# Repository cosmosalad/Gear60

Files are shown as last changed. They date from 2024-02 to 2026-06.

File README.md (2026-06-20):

[▶ Check Out GearSeries](https://github.com/cosmosalad/GearSeries)<br/>
[프로젝트 과정(kr)](https://blog.naver.com/cosmosalad/223262540878)<br/><br/>

# Gear60<br/>
Gear60 is a 60% multi-layout keyboard based on the rp2040.
<br/>

It's mostly compatible with 60% layout keyboards. Just modify usb and plate to suit your keyboard housing

<br/>

<p align="center">
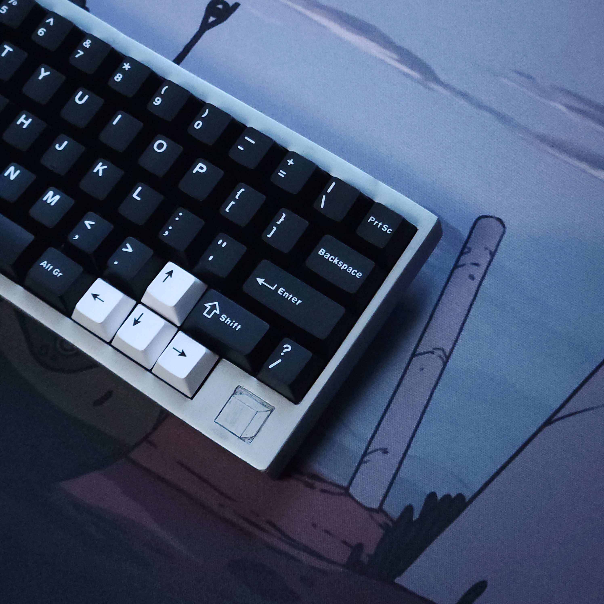
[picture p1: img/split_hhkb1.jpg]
  
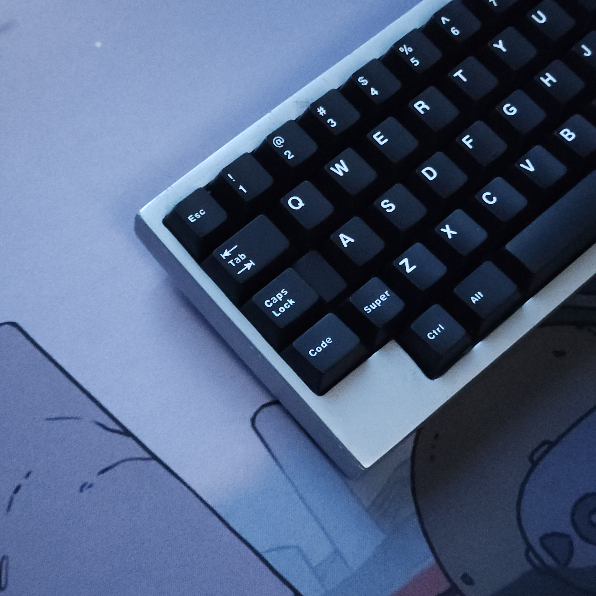
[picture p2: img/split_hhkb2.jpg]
  
</p>
<p align="center">
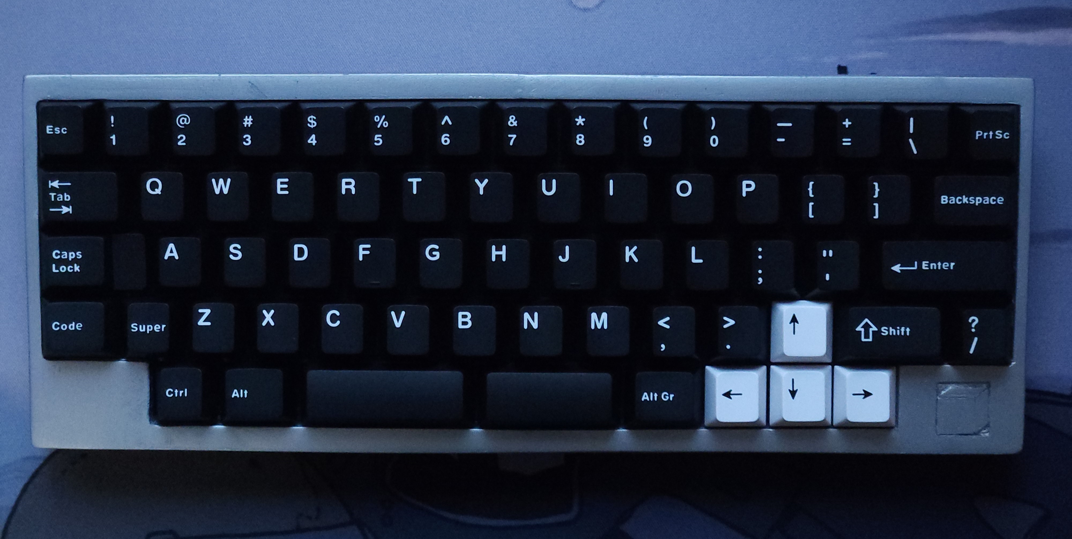
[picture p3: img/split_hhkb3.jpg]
  
</p>

split_hhkb (fdm print)

<br/><br/>

<p align="center">
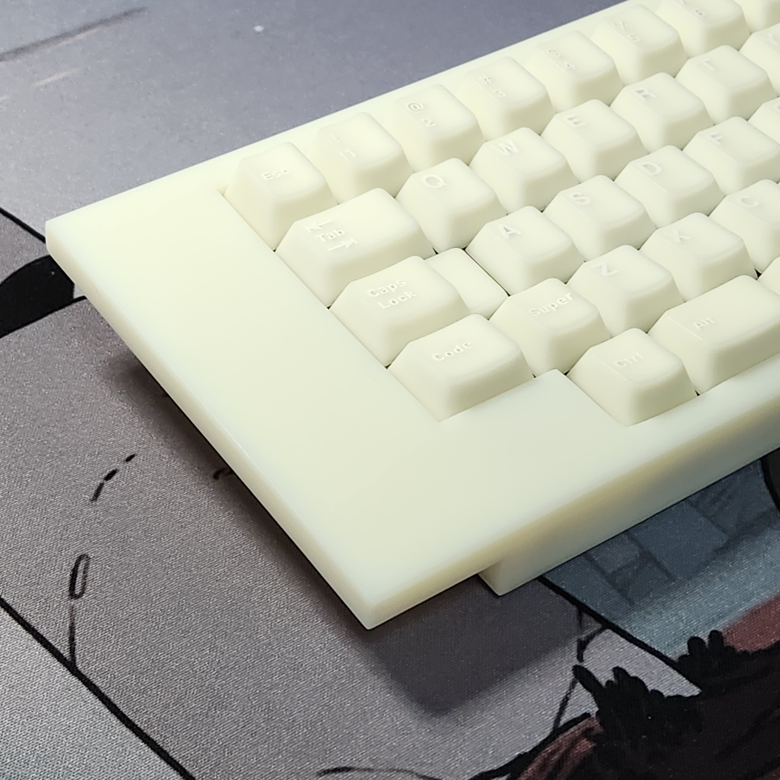
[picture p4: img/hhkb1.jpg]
  
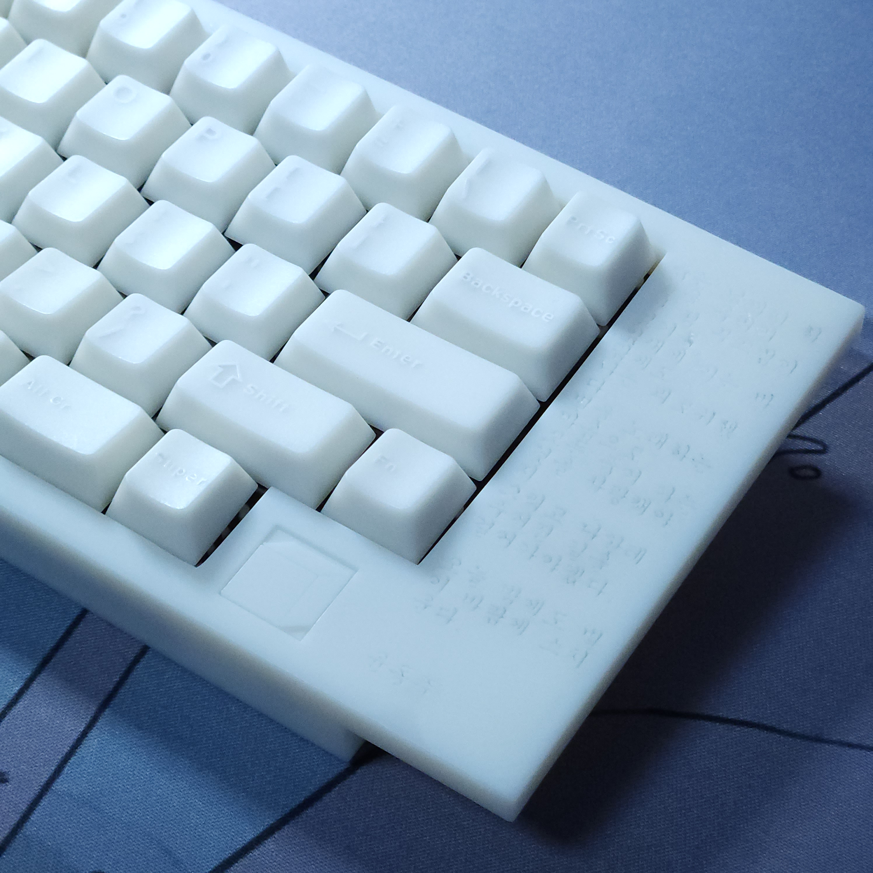
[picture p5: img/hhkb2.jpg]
  
</p>
<p align="center">
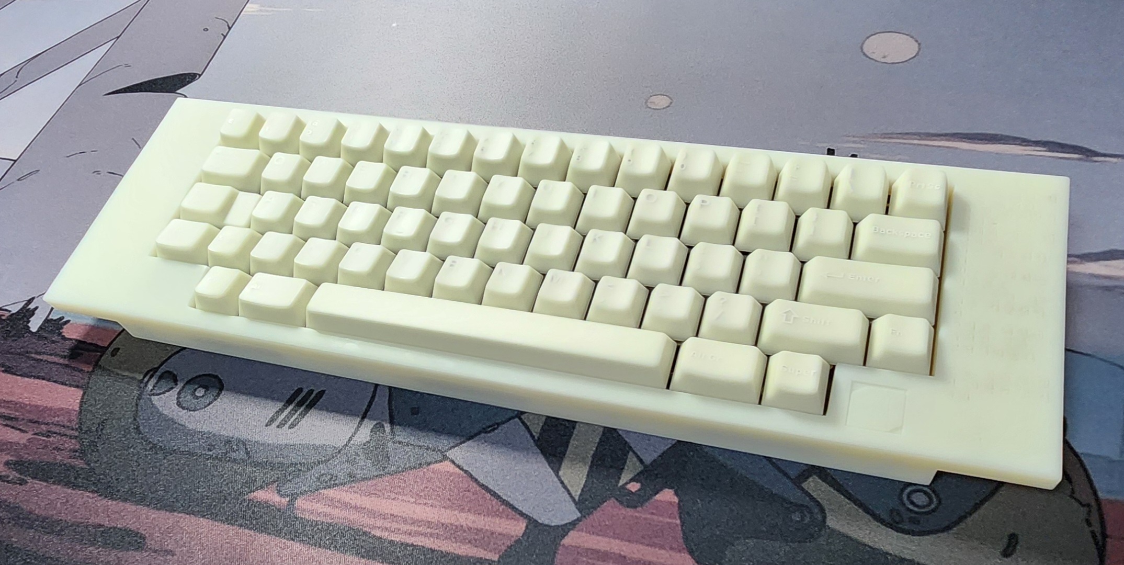
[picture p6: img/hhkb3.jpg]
  
</p>

hhkb - B type (sla print)

<br/><br/>

## Layout<br/>

- solder<br/>
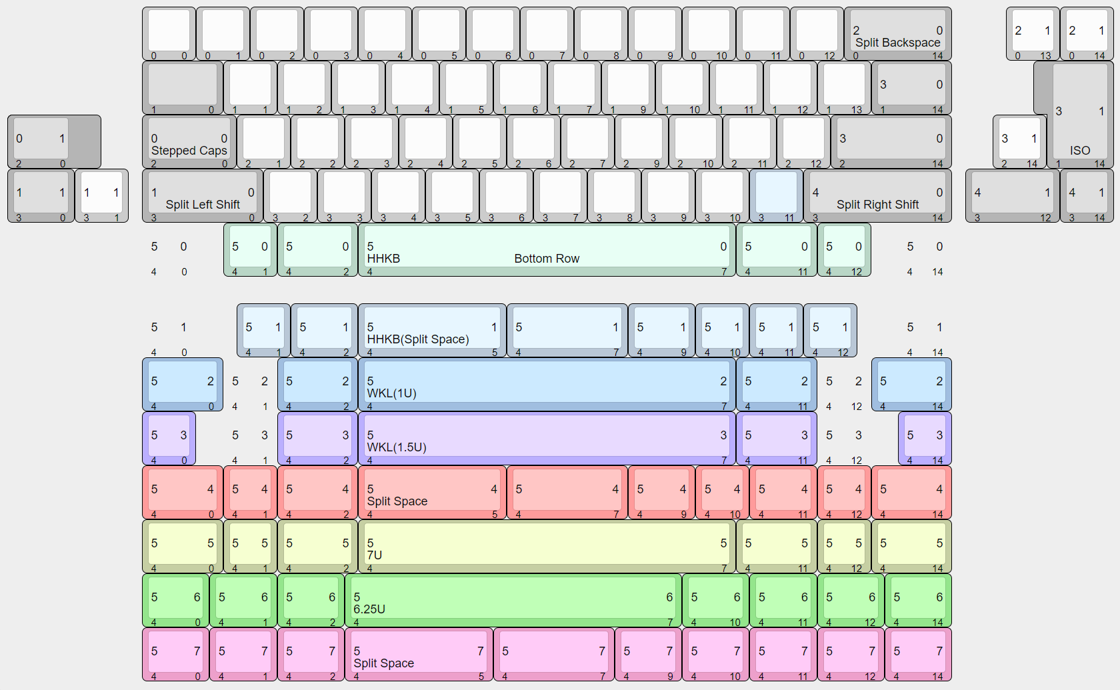
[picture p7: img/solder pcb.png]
solder pcb

<br/><br/>

- hotswap<br/>
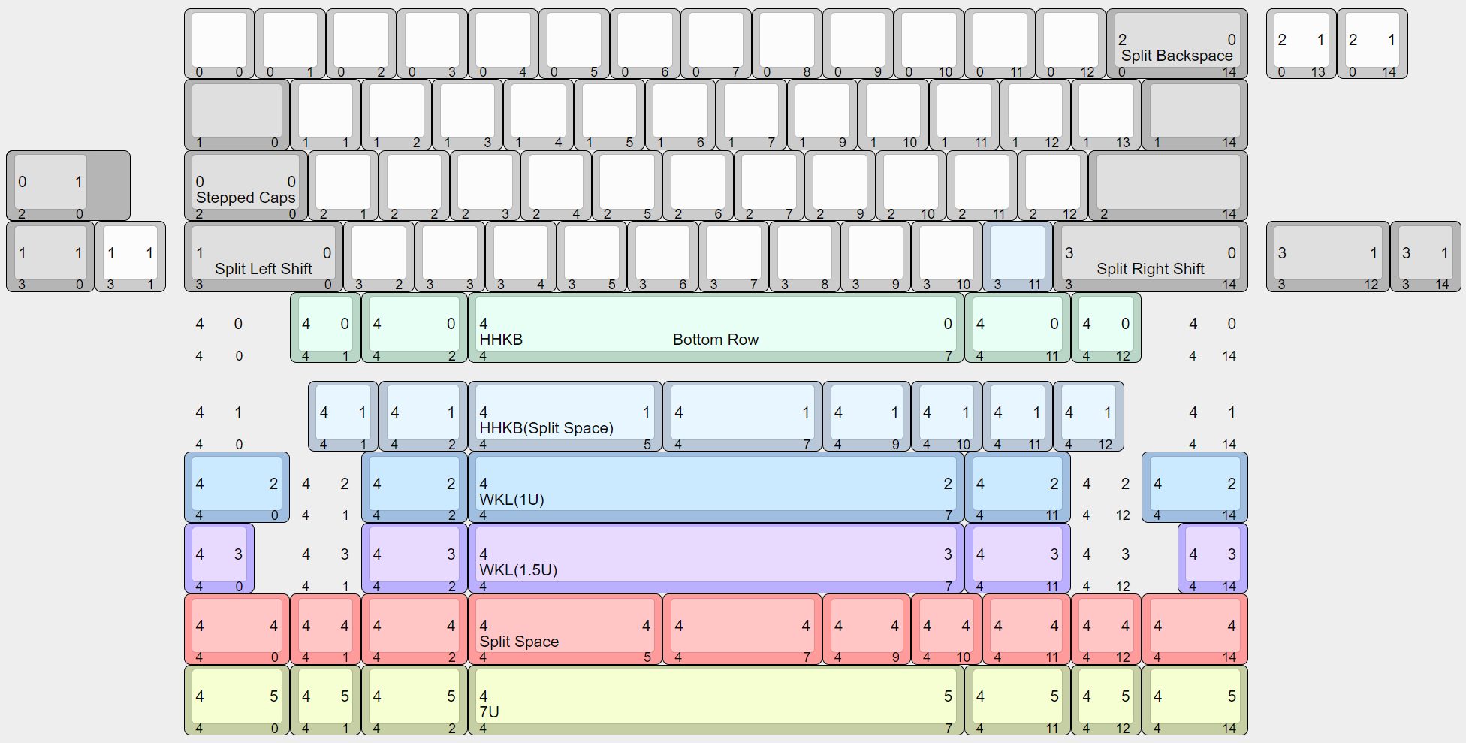
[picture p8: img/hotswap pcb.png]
hotswap pcb

<br/><br/>

There is also a [keyboard plate](https://github.com/cosmosalad/Gear60/tree/main/plate).<br/>
[Keyboard case](https://github.com/cosmosalad/Gear60/tree/main/case) corresponding to this layout.<br/>

<br/><br/>

## PCB<br/>
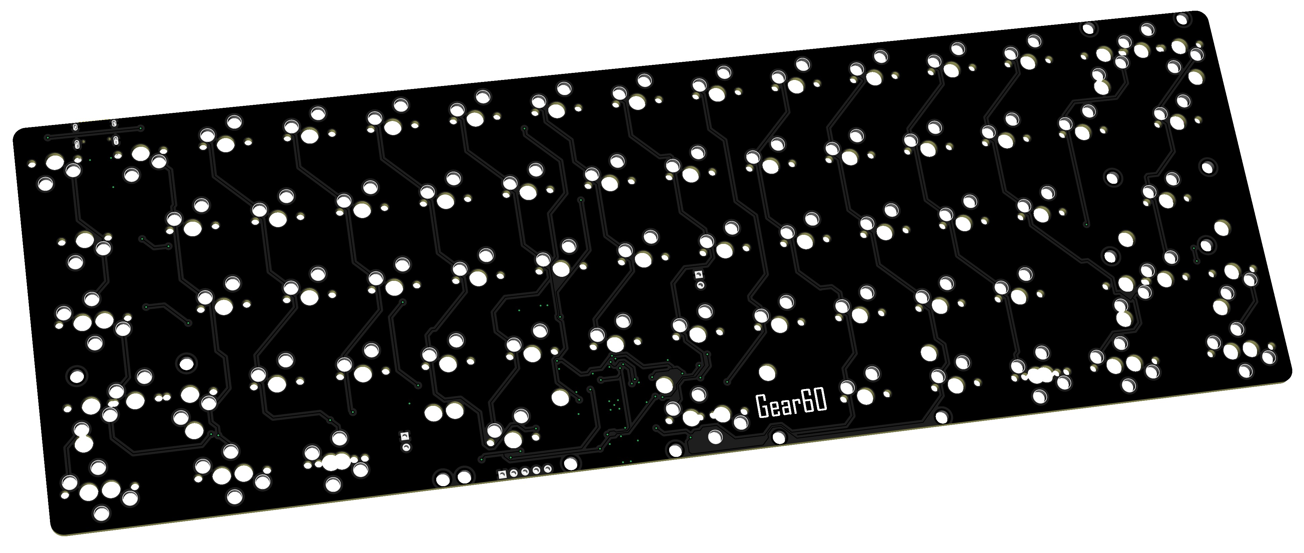
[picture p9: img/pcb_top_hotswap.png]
pcb_top_hotswap
<br/>
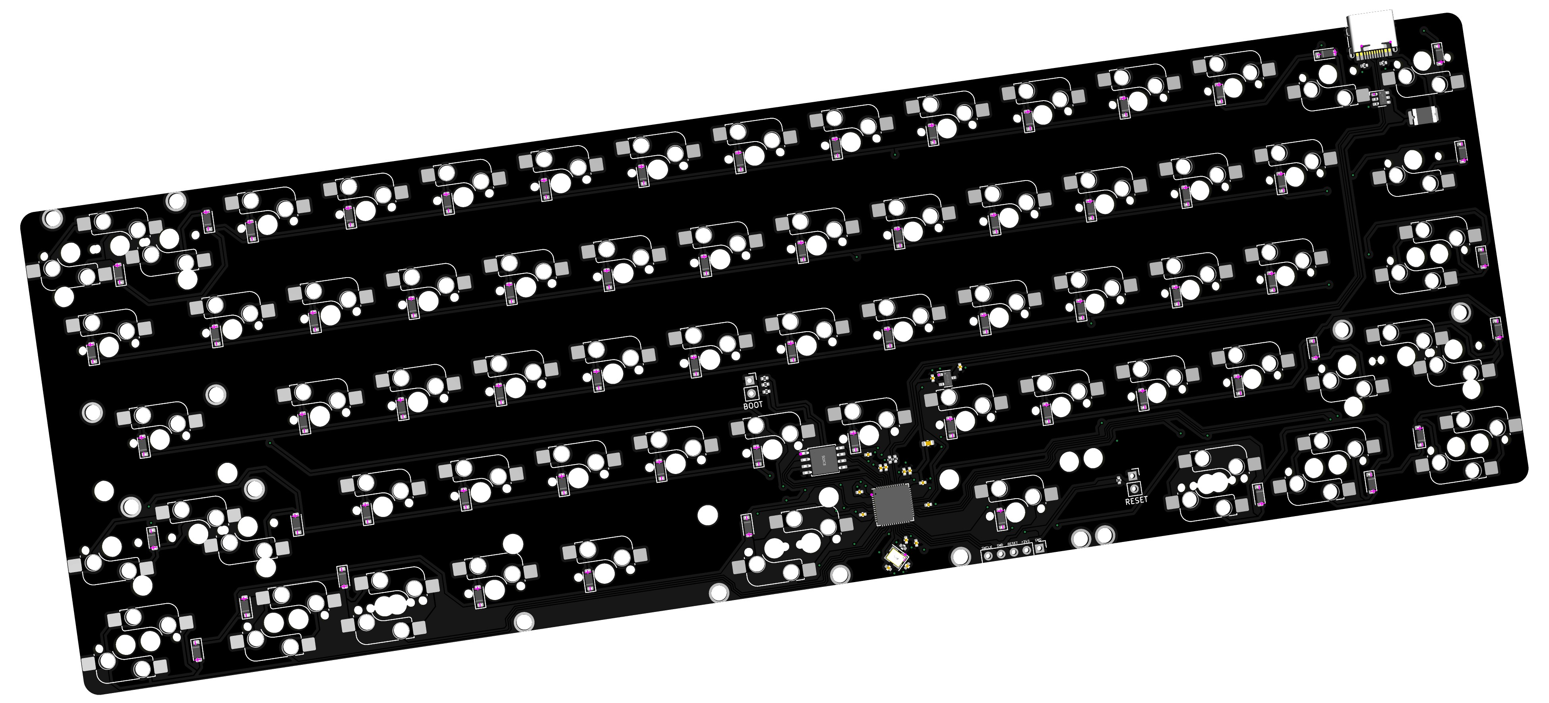
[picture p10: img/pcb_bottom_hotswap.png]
pcb_bottom_hotswap
<br/><br/><br/>

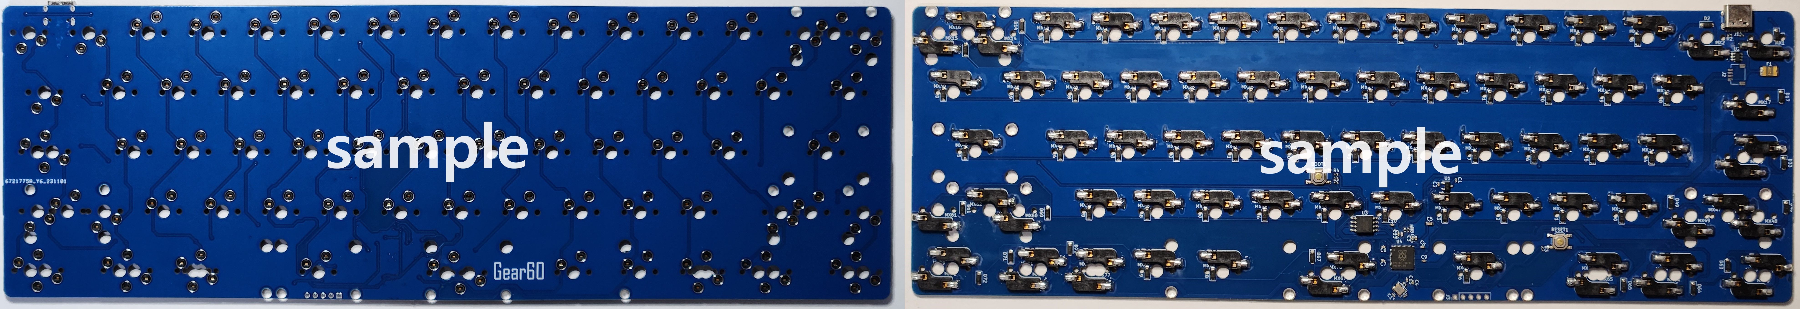
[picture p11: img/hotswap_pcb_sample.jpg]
hotswap_pcb_sample
<br/>
There is a change from the initial pcb design. [More pcb](https://github.com/cosmosalad/Gear60/tree/main/pcb)<br/><br/>
This pcb was made by jlcpcb.([list of pcb parts](https://github.com/cosmosalad/Gear60/blob/main/pcb/hotswap/part%20list.md))<br/><br/>
This pcb prepared the [vial](https://github.com/cosmosalad/Gear60/tree/main/vial) as firmware<br/><br/>

<p align="center">
  <a href="https://youtube.com/embed/gBcXavTLRE8">
    gear60
  </a>
</p>
<br/>

## Reference<br/>
- [keyboard-layout-editor](http://www.keyboard-layout-editor.com/)<br/>
- [Hardware design with RP2040](https://datasheets.raspberrypi.com/rp2040/hardware-design-with-rp2040.pdf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..), [Hardware design for the RP2040](https://github.com/Sleepdealr/RP2040-designguide)<br/>
- [kicad](https://www.kicad.org/), [marbastlib](https://github.com/ebastler/marbastlib), [kleeb](https://github.com/crides/kleeb)<br/>
- [KiCAD KLE Placer](https://github.com/zykrah/kicad-kle-placer), [Firmware 'scripts'](https://github.com/zykrah/firmware-scripts)<br/>
- [vial](https://get.vial.today/), [qmk](https://qmk.fm/)<br/>
- [ai03 Plate Generator v2](https://github.com/ai03-2725/yet-another-keyboard-builder)<br/>

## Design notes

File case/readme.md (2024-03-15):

### gear60_top_split_hhkb<br/>
gear60_top_split_hhkb
<br/><br/><br/><br/><br/>

### gear60_top_wkl<br/>
gear60_top_wkl
<br/><br/><br/><br/><br/>

### gear60_top<br/>
gear60_top
<br/><br/><br/><br/><br/>

### gear60_top_hhkb<br/>
gear60_top_hhkb
<br/><br/><br/><br/><br/>

### gear60_top_split_hhkb - A type<br/>
top_split_hhkb_a-type<br/>
a-type
<br/><br/><br/><br/><br/>

### gear60_top_hhkb - B type<br/>
top_hhkb_b-type
<br/><br/><br/><br/><br/>

### gear60_bottom<br/>
gear60_bottom
<br/><br/><br/><br/><br/>

### gear60_top_rp2040zero, bottom_rp2040zero<br/>
top_rp2040zero

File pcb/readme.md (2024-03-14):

### Gear60 hotswap<br/>
Gear60 hotswap<br/>

<br/><br/>

### Gear60 solder<br/>
Gear60 solder<br/>

<br/><br/>

### Gear60 solder_rp2040zero<br/>
solder_rp2040zero<br/>

<br/><br/>

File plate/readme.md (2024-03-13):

plate

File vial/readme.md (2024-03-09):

Hold the boot button and connect usb.<br/>

usb<br/>
After connecting to the keyboard, add the [uf2 file]https://github.com/cosmosalad/Gear60/tree/main/vial).<br/><br/><br/>

Open the [vial](https://vial.rocks/).<br/>
vial test<br/>
Key map<br/><br/>

test1<br/>
You can select the layout.<br/><br/>

test2<br/>

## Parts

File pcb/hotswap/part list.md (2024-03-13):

| **Comment** | **Designator** | **Footprint** | **JLCPCB Part #** |
|:---:|:---:|:---:|:---:|
| D_Small | ALL D | Diode_SMD:D_SOD-123 | C2099 |
| 22pF | C11,C12 | Capacitor_SMD:C_0402_1005Metric | C147430 |
| 10uF | C5 | Capacitor_SMD:C_0603_1608Metric | C19702 |
| 1uF | C1,C2,C3,C6,C10 | CAP-SMD_BD5.0-L5.3-W5.3-LS6.3-FD | C15684 |
| 100nF | C4,C7,C8,C9,C13,C14,C15,C16 | Capacitor_SMD:C_0402_1005Metric | C1525 |
| 27Ω | R7,R8 | Resistor_SMD:R_0402_1005Metric | C138021 |
| 5.1kΩ | R1,R2,R3,R4,R5 | Resistor_SMD:R_0402_1005Metric | C25905 |
| 1kΩ | R6,R9 | Resistor_SMD:R_0402_1005Metric | C11702 |
| RP2040 | U4 | Package_DFN_QFN:QFN-56-1EP_7x7mm_P0.4mm_EP3.2x3.2mm | C2040 |
| W25Q128JVS | U3 | Package_SO:SOIC-8_5.23x5.23mm_P1.27mm | C97521 |
| USB_C_Receptacle_USB2.0 | J1 | Connector_USB:USB_C_Receptacle_HRO_TYPE-C-31-M-12 | C165948 |
| XC6206P332MR	 | U1 | Package_TO_SOT_SMD:SOT-23-3 | C5446 |
| Crystal_GND24 | Y1 | Crystal:Crystal_SMD_3225-4Pin_3.2x2.5mm | C9002 |
| SRV05-4 | U2 | PCM_marbastlib-various:SOT-23-6-routable | C7420376 |
| MF-MSMF050-2500mA | F1 | Fuse:Fuse_0603_1608Metric | C17313 |

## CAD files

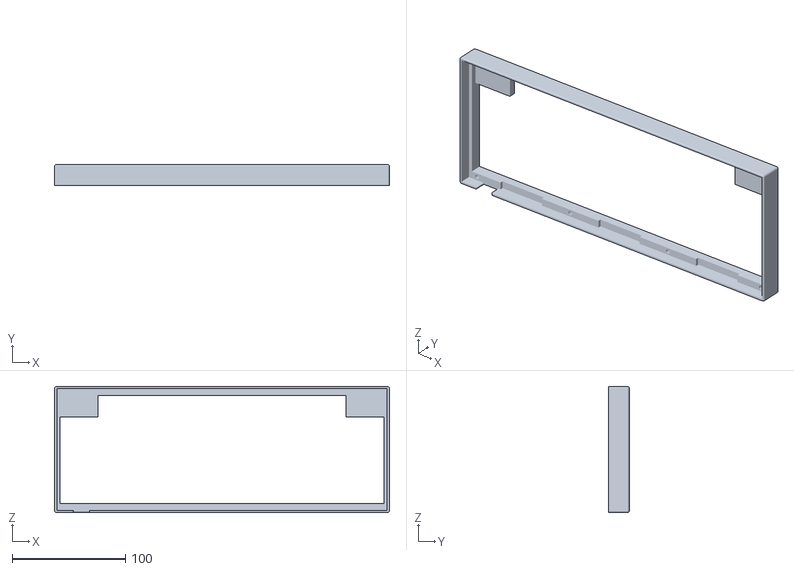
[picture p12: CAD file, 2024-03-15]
case/top_split_hhkb.stl
296.2 x 19.0 x 111.4

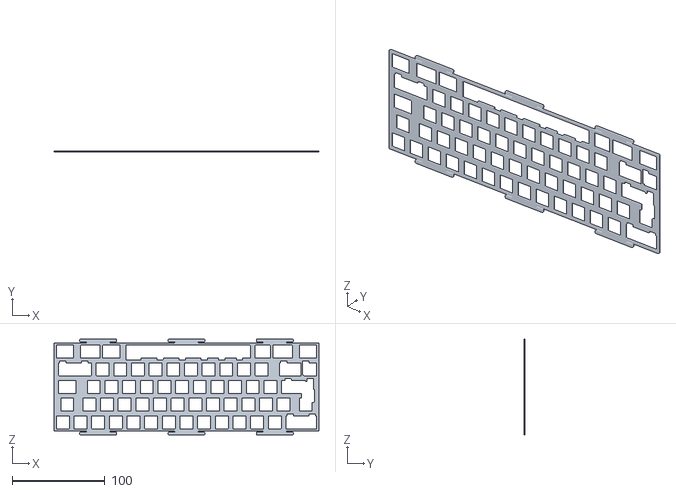
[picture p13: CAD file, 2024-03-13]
plate/gear60_plate.stl
285.8 x 1.50 x 103.2

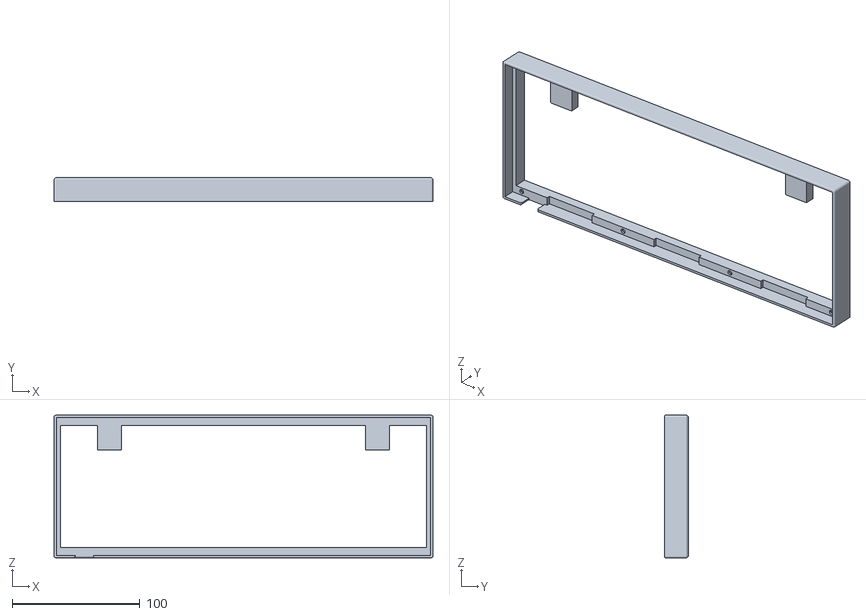
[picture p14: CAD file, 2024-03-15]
case/top_wkl.stl
296.2 x 19.0 x 111.4

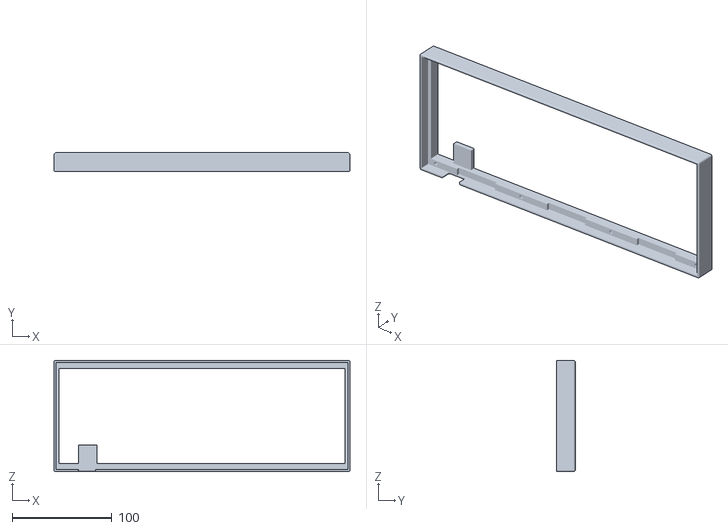
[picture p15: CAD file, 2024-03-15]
case/top_rp2040zero.stl
296.2 x 19.0 x 111.4

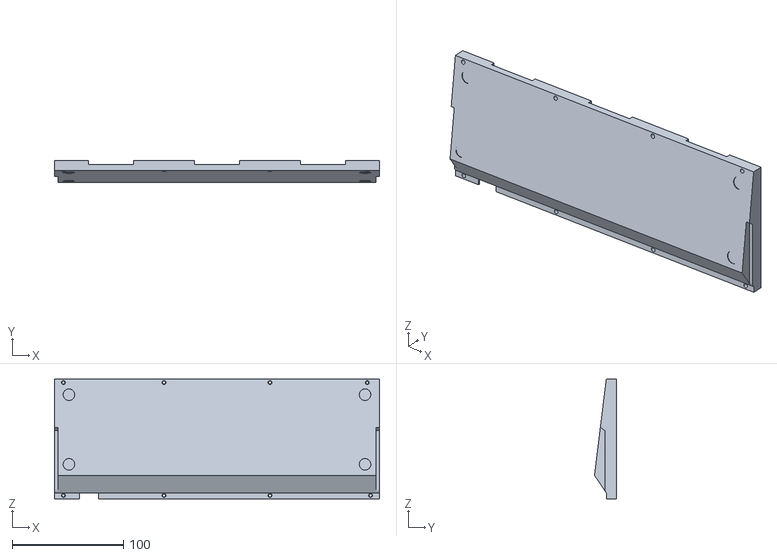
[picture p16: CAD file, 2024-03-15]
case/bottom_rp2040zero.stl
292.2 x 19.9 x 107.4

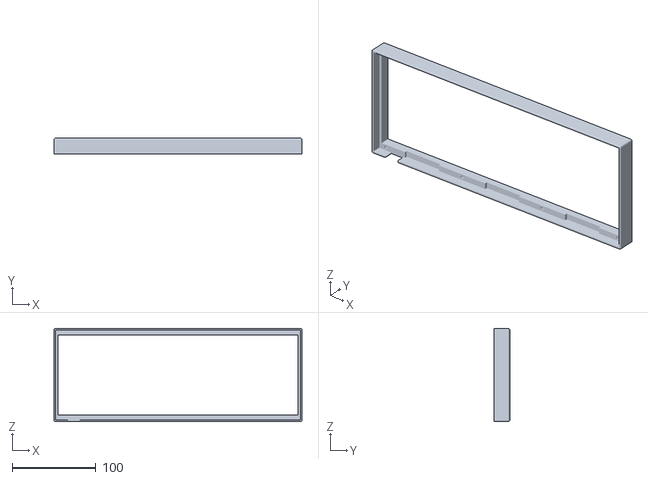
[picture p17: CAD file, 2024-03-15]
case/top.stl
296.2 x 19.0 x 111.4

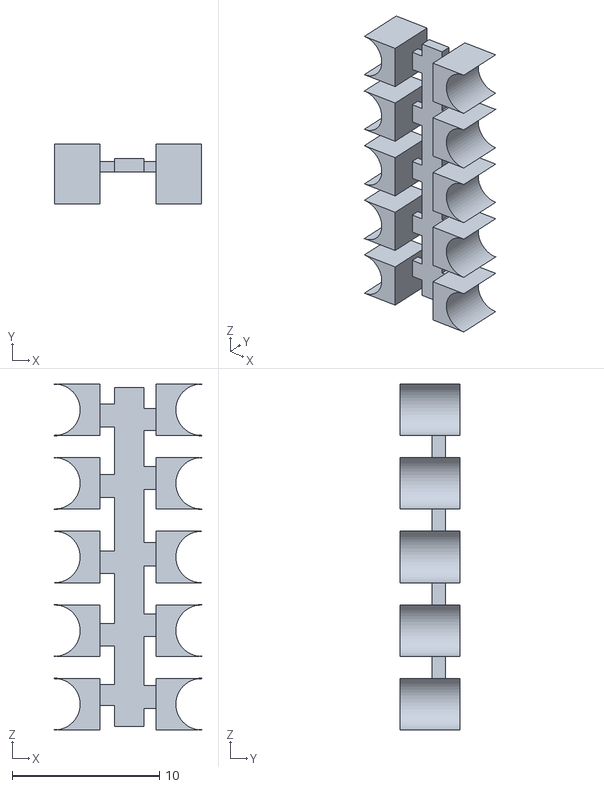
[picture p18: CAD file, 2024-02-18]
case/a-type.stl
10.0 x 4.10 x 23.5

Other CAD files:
case/top_hhkb.stl
case/top_split_hhkb_a-type.stl
case/bottom.stl
plate/gear60_plate.dxf

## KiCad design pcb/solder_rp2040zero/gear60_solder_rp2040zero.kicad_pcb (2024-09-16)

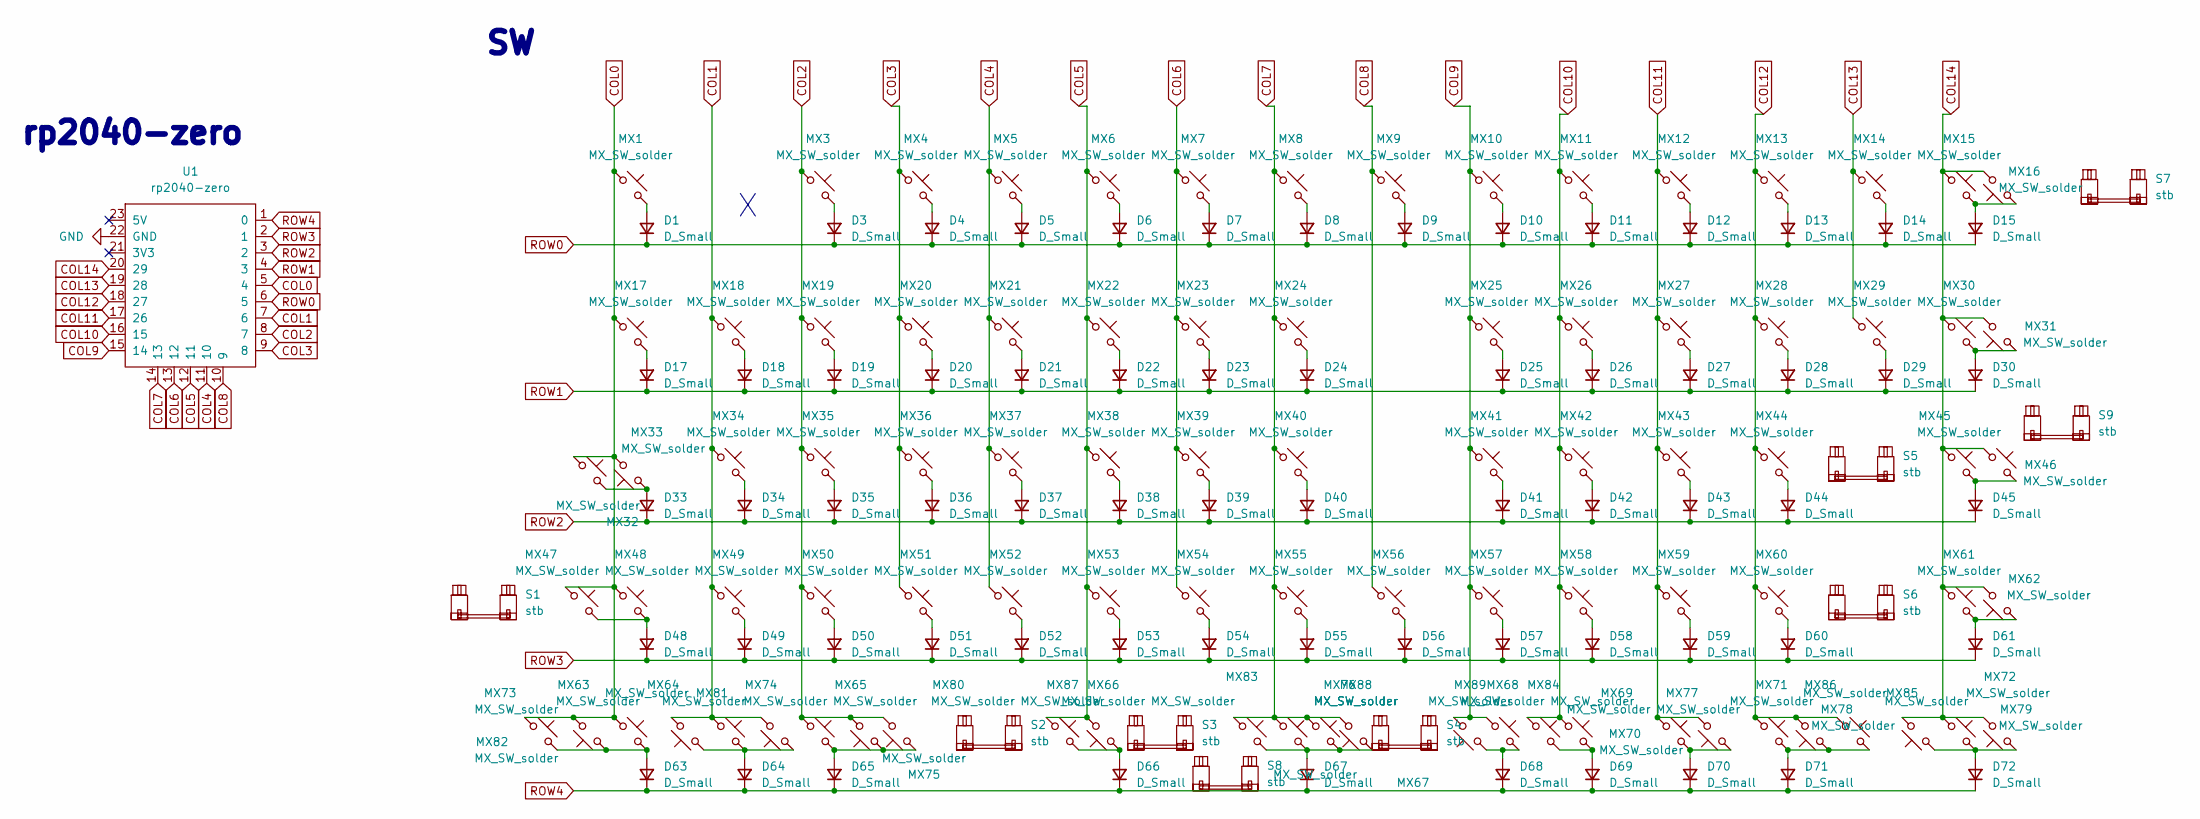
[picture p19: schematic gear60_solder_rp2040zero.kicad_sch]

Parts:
D1, D3, D4, D5, D6, D7, D8, D9, D10, D11, D12, D13, D14, D15, D17, D18, D19, D20, D21, D22, D23, D24, D25, D26, D27, D28, D29, D30, D33, D34, D35, D36, D37, D38, D39, D40, D41, D42, D43, D44, D45, D48, D49, D50, D51, D52, D53, D54, D55, D56, D57, D58, D59, D60, D61, D63, D64, D65, D66, D67, D68, D69, D70, D71, D72: D_Small; D_SOD-123
MX1, MX3, MX4, MX5, MX6, MX7, MX8, MX9, MX10, MX11, MX12, MX13, MX14, MX15, MX16, MX18, MX19, MX20, MX21, MX22, MX23, MX24, MX25, MX26, MX27, MX28, MX29, MX31, MX34, MX35, MX36, MX37, MX38, MX39, MX40, MX41, MX42, MX43, MX44, MX45, MX46, MX47, MX49, MX50, MX51, MX52, MX53, MX54, MX55, MX56, MX57, MX58, MX59, MX61, MX62, MX63, MX64, MX66, MX67, MX69, MX70, MX71, MX72, MX74, MX76, MX78, MX83, MX87, MX88, MX89: MX_SW_solder; SW_MX_1u
MX17, MX30, MX73, MX75, MX79: MX_SW_solder; SW_MX_1.5u
MX32: MX_SW_solder; SW_MX_1.75u_STP_1.25
MX33, MX60: MX_SW_solder; SW_MX_1.75u
MX48, MX65, MX68, MX77, MX80, MX81, MX82, MX84, MX85, MX86: MX_SW_solder; SW_MX_1.25u
S1, S3, S5: stb; STAB_MX_P_2.25u
S2, S6: stb; STAB_MX_P_2.75u
S4: stb; STAB_MX_P_7u
S7: stb; STAB_MX_P_2u
S8: stb; STAB_MX_P_6.25u
S9: stb; STAB_MX_ISO
U1: rp2040-zero; rp2040-zero-tht-new_long

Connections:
COL0: MX1.1, MX17.1, MX32.1, MX33.2, MX47.1, MX48.1, MX63.1, MX73.2, MX82.1, U1.5 (4)
COL1: MX18.1, MX34.1, MX49.1, MX64.1, MX74.2, MX81.2, U1.7 (6)
COL2: MX3.1, MX19.1, MX35.1, MX50.1, MX65.1, MX75.2, MX80.2, U1.8 (7)
COL3: MX4.1, MX20.1, MX36.1, MX51.1, U1.9 (8)
COL4: MX5.1, MX21.1, MX37.1, MX52.1, U1.11 (10)
COL5: MX6.1, MX22.1, MX38.1, MX53.1, MX66.2, MX87.1, U1.12 (11)
COL6: MX7.1, MX23.1, MX39.1, MX54.1, U1.13 (12)
COL7: MX8.1, MX24.1, MX40.1, MX55.1, MX67.1, MX76.1, MX83.1, MX88.2, U1.14 (13)
COL8: MX9.1, MX56.1, U1.10 (9)
COL9: MX10.1, MX25.1, MX41.1, MX57.1, MX68.1, MX89.2, U1.15 (14)
COL10: MX11.1, MX26.1, MX42.1, MX58.1, MX69.1, MX84.1, U1.16 (15)
COL11: MX12.1, MX27.1, MX43.1, MX59.1, MX70.1, MX77.2, U1.17 (26)
COL12: MX13.1, MX28.1, MX44.1, MX60.1, MX71.1, MX78.2, MX86.1, U1.18 (27)
COL13: MX14.1, MX29.1, U1.19 (28)
COL14: MX15.1, MX16.2, MX30.1, MX31.2, MX45.1, MX46.1, MX61.1, MX62.2, MX72.1, MX79.2, MX85.2, U1.20 (29)
GND: U1.22 (GND)
unnamed: D1.2 (A), MX1.2
unnamed: D3.2 (A), MX3.2
unnamed: D4.2 (A), MX4.2
unnamed: D5.2 (A), MX5.2
unnamed: D6.2 (A), MX6.2
unnamed: D7.2 (A), MX7.2
unnamed: D8.2 (A), MX8.2
unnamed: D9.2 (A), MX9.2
unnamed: D10.2 (A), MX10.2
unnamed: D11.2 (A), MX11.2
unnamed: D12.2 (A), MX12.2
unnamed: D13.2 (A), MX13.2
unnamed: D14.2 (A), MX14.2
unnamed: D15.2 (A), MX15.2, MX16.1
unnamed: D17.2 (A), MX17.2
unnamed: D18.2 (A), MX18.2
unnamed: D19.2 (A), MX19.2
unnamed: D20.2 (A), MX20.2
unnamed: D21.2 (A), MX21.2
unnamed: D22.2 (A), MX22.2
unnamed: D23.2 (A), MX23.2
unnamed: D24.2 (A), MX24.2
unnamed: D25.2 (A), MX25.2
unnamed: D26.2 (A), MX26.2
unnamed: D27.2 (A), MX27.2
unnamed: D28.2 (A), MX28.2
unnamed: D29.2 (A), MX29.2
unnamed: D30.2 (A), MX30.2, MX31.1
unnamed: D33.2 (A), MX32.2, MX33.1
unnamed: D34.2 (A), MX34.2
unnamed: D35.2 (A), MX35.2
unnamed: D36.2 (A), MX36.2
unnamed: D37.2 (A), MX37.2
unnamed: D38.2 (A), MX38.2
unnamed: D39.2 (A), MX39.2
unnamed: D40.2 (A), MX40.2
unnamed: D41.2 (A), MX41.2
unnamed: D42.2 (A), MX42.2
unnamed: D43.2 (A), MX43.2
unnamed: D44.2 (A), MX44.2
unnamed: D45.2 (A), MX45.2, MX46.2
unnamed: D48.2 (A), MX47.2, MX48.2
unnamed: D49.2 (A), MX49.2
unnamed: D50.2 (A), MX50.2
unnamed: D51.2 (A), MX51.2
unnamed: D52.2 (A), MX52.2
unnamed: D53.2 (A), MX53.2
unnamed: D54.2 (A), MX54.2
unnamed: D55.2 (A), MX55.2
unnamed: D56.2 (A), MX56.2
unnamed: D57.2 (A), MX57.2
unnamed: D58.2 (A), MX58.2
unnamed: D59.2 (A), MX59.2
unnamed: D60.2 (A), MX60.2
unnamed: D61.2 (A), MX61.2, MX62.1
unnamed: D63.2 (A), MX63.2, MX73.1, MX82.2
unnamed: D64.2 (A), MX64.2, MX74.1, MX81.1
unnamed: D65.2 (A), MX65.2, MX75.1, MX80.1
unnamed: D66.2 (A), MX66.1, MX87.2
unnamed: D67.2 (A), MX67.2, MX76.2, MX83.2, MX88.1
unnamed: D68.2 (A), MX68.2, MX89.1
unnamed: D69.2 (A), MX69.2, MX84.2
unnamed: D70.2 (A), MX70.2, MX77.1
unnamed: D71.2 (A), MX71.2, MX78.1, MX86.2
unnamed: D72.2 (A), MX72.2, MX79.1, MX85.1
ROW0: D1.1 (K), D3.1 (K), D4.1 (K), D5.1 (K), D6.1 (K), D7.1 (K), D8.1 (K), D9.1 (K), D10.1 (K), D11.1 (K), D12.1 (K), D13.1 (K), D14.1 (K), D15.1 (K), U1.6 (5)
ROW1: D17.1 (K), D18.1 (K), D19.1 (K), D20.1 (K), D21.1 (K), D22.1 (K), D23.1 (K), D24.1 (K), D25.1 (K), D26.1 (K), D27.1 (K), D28.1 (K), D29.1 (K), D30.1 (K), U1.4 (3)
ROW2: D33.1 (K), D34.1 (K), D35.1 (K), D36.1 (K), D37.1 (K), D38.1 (K), D39.1 (K), D40.1 (K), D41.1 (K), D42.1 (K), D43.1 (K), D44.1 (K), D45.1 (K), U1.3 (2)
ROW3: D48.1 (K), D49.1 (K), D50.1 (K), D51.1 (K), D52.1 (K), D53.1 (K), D54.1 (K), D55.1 (K), D56.1 (K), D57.1 (K), D58.1 (K), D59.1 (K), D60.1 (K), D61.1 (K), U1.2 (1)
ROW4: D63.1 (K), D64.1 (K), D65.1 (K), D66.1 (K), D67.1 (K), D68.1 (K), D69.1 (K), D70.1 (K), D71.1 (K), D72.1 (K), U1.1 (0)

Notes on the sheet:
rp2040-zero

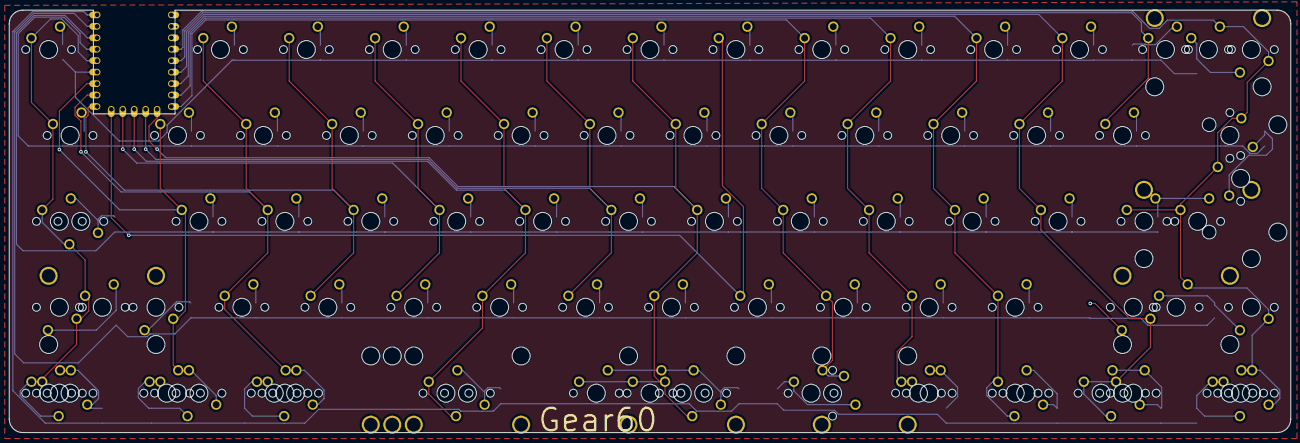
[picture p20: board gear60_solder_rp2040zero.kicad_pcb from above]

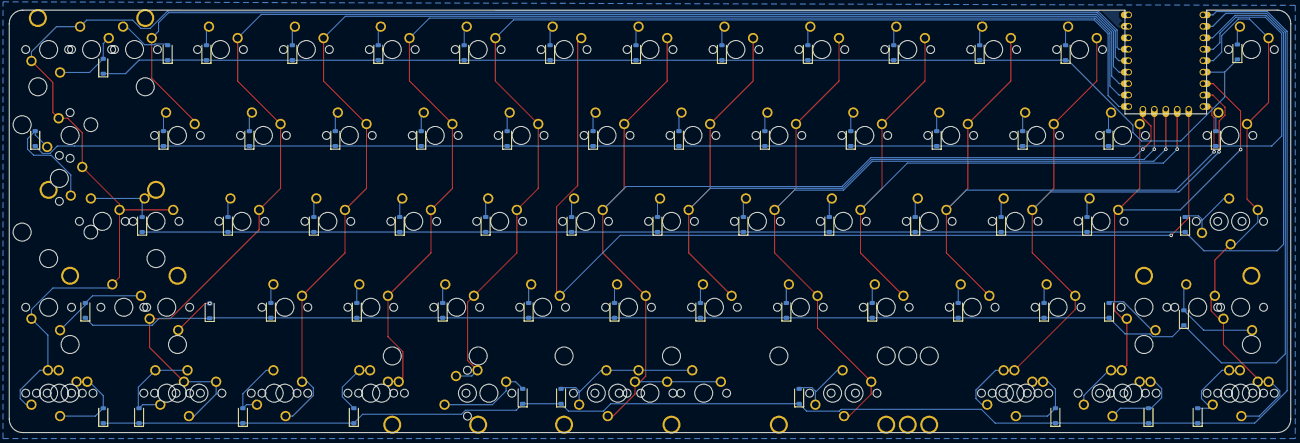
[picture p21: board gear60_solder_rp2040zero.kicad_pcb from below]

Board: 2 copper layers, 284.2 x 93.7 mm, 163 parts (66 on the bottom side), 85 nets.

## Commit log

2024-02-18 Rename gear60 plate.stl to gear60_plate.stl
    [gear60_plate.stl]
2024-02-18 Update and rename gear60 plate.dxf to gear60_plate.dxf
    [gear60_plate.dxf]
2024-02-19 Update and rename gear60_hs_bow.csv to gear60_hs_bow.csv
    [gear60_hs_bow.csv]
2024-02-19 Update and rename gear60_hs_cpl.csv to gear60_hs_cpl.csv
    [gear60_hs_cpl.csv]
2024-02-19 Update and rename gear60_solder_bow.csv to gear60_solder_bow.csv
    [gear60_solder_bow.csv]
2024-02-19 Update and rename gear60_solder_cpl.csv to gear60_solder_cpl.csv
    [gear60_solder_cpl.csv]
2024-02-21 Update and rename gear60_hs_cpl.csv to gear60_solder_cpl.csv
    [gear60_solder_cpl.csv]
